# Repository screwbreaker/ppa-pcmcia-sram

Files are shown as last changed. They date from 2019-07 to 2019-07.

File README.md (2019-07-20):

# SAKURA, Amiga pcmcia sram
4MB of Fast RAM for unexpanded Amiga 600/1200.
Original desig by Jarosław Bieliński and Radosław Kujawa.
The informations about the original version of this board can be found here: https://github.com/Sakura-IT/ppa-pcmcia-sram

Since the original version, some components, like the RAM, are became difficult to find, so, many revisions of this board was made in order to use available components.
In 2018 the project was updated again and ported to KiCad by jensma: https://github.com/jensma/ppa-pcmcia-sram
This revision is based on his work.

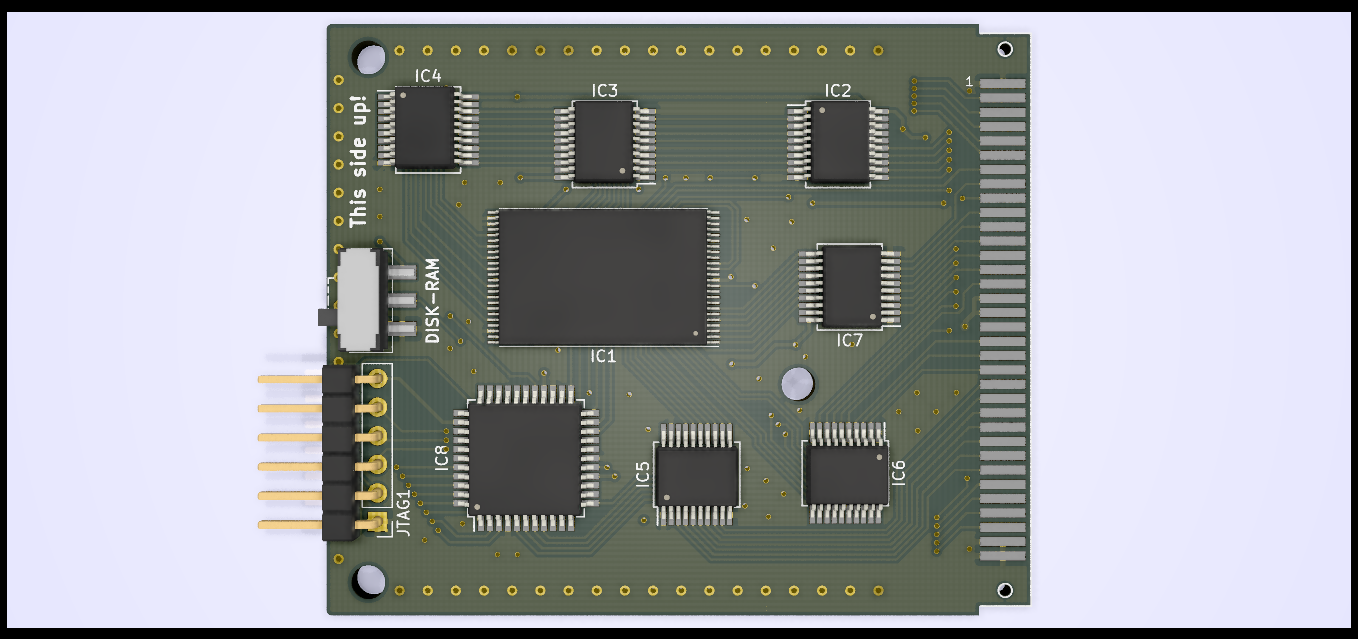
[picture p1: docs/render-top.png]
Board


### Summary
Some components like the RAM are available but not cheap. On the jensma revision also the PCB was not cheap, because he used small tracks and vias.
The main goal of this revision is to made the PCB as cheaper as possible. This make this expansion a little more affordable.

#### BOM
- C14,C3,C5,C6,C7,C8,C9,C10,C11,C12,C13,C4 100nF 0805 ceramic capacitor
- C1,C2: >=10uF >=6,3V 1206 tantalum capacitor
- U1: LM1117-3.3 voltage regulator
- IC2,IC3, IC4 74LCX245MTC
- IC5,IC6,IC7: 74LCX541TTR
- IC1: AS6C3216-55, SRAM
- IC8: XC9536XL_44VQ CPLD
- PCMCIA connector 95622-004LF
- SW1: SW_SPDT_CK-JS102011SAQN

### Installation
Since this board don't have a proper PCMCIA case it must be inserted carefully.
Do not apply too much force, or the pin iside the Amiga connector can be damaged.
There is a maker on the board to identify the upper side.

### License
This board is Open Hardware. If you make any modifications to the board, please contribute them back.

### Disclaimer
This board is provided to you 'as is' and without any express or implied warranties whatsoever with respect to its functionality, operability or use, including, without limitation, any implied warranties of merchantability, fitness for a particular purpose or infringement. We expressly disclaim any liability whatsoever for any direct, indirect, consequential, incidental or special damages, including, without limitation, lost revenues, lost profits, losses resulting from business interruption or loss of data, regardless of the form of action or legal theory under which the liability may be asserted, even if advised of the possibility or likelihood of such damages.

### Thanks
- A special Thanks to: [EmberHeavyIndustries](https://github.com/EmberHeavyIndustries) for the help in the development.
- DanyPPC who started the discussion, [SukkoPera](https://github.com/SukkoPera), Mck, and all the other guys on the Italian Amiga forum [Amigapage](https://www.amigapage.it/index.php?op=v&pl=forum&id=F012019-2-9&page=1)

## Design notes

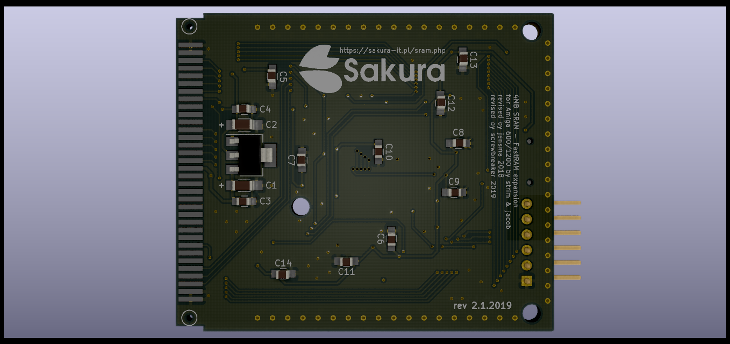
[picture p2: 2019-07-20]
docs/render-bottom.png

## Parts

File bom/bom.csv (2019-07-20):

Id | Designator | Package | Quantity | Designation | Supplier and ref
1 | SW1 | SW_SPDT_CK-JS102011SAQN | 1 | RAM/Disk
2 | C14,C3,C5,C6,C7,C8,C9,C10,C11,C12,C13,C4 | C_0805_HandSoldering | 12 | 0,1uF
3 | C1,C2 | C_1206_HandSoldering | 2 | 10uF/6,3V
4 | U1 | SOT-223-3_TabPin2 | 1 | LM1117-3.3
5 | IC2,IC3,IC4 | SSOP-20_5.3x7.2mm_Pitch0.65mm | 3 | 74LCX245MTC
6 | IC5,IC6,IC7 | SSOP-20_5.3x7.2mm_Pitch0.65mm | 3 | 74LCX541TTR
7 | JTAG1 | Socket_Strip_Straight_1x06_Pitch2.54mm | 1 | MA06-1
8 | X1 | pcmcia | 1 | PCMCIA female
9 | IC1 | TSOP-I-48_18.4x12mm_Pitch0.5mm | 1 | AS6C3216-55
10 | IC8 | TQFP-44_10x10mm_Pitch0.8mm | 1 | XC9536XL_44VQ

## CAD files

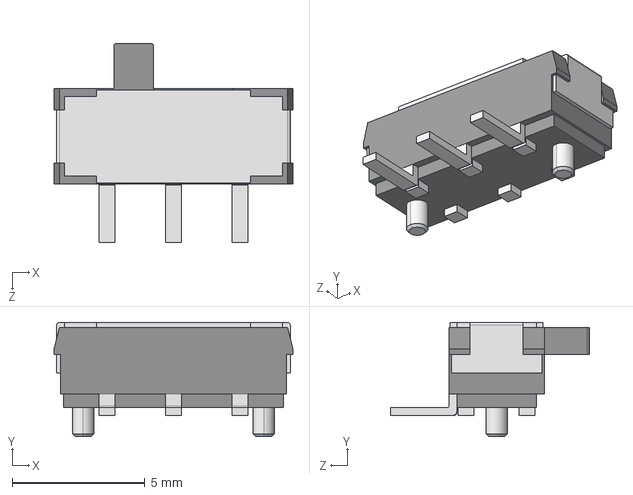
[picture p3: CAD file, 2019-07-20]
3Dmodels/JS102011SAQN.STEP
9.00 x 4.30 x 7.50 mm

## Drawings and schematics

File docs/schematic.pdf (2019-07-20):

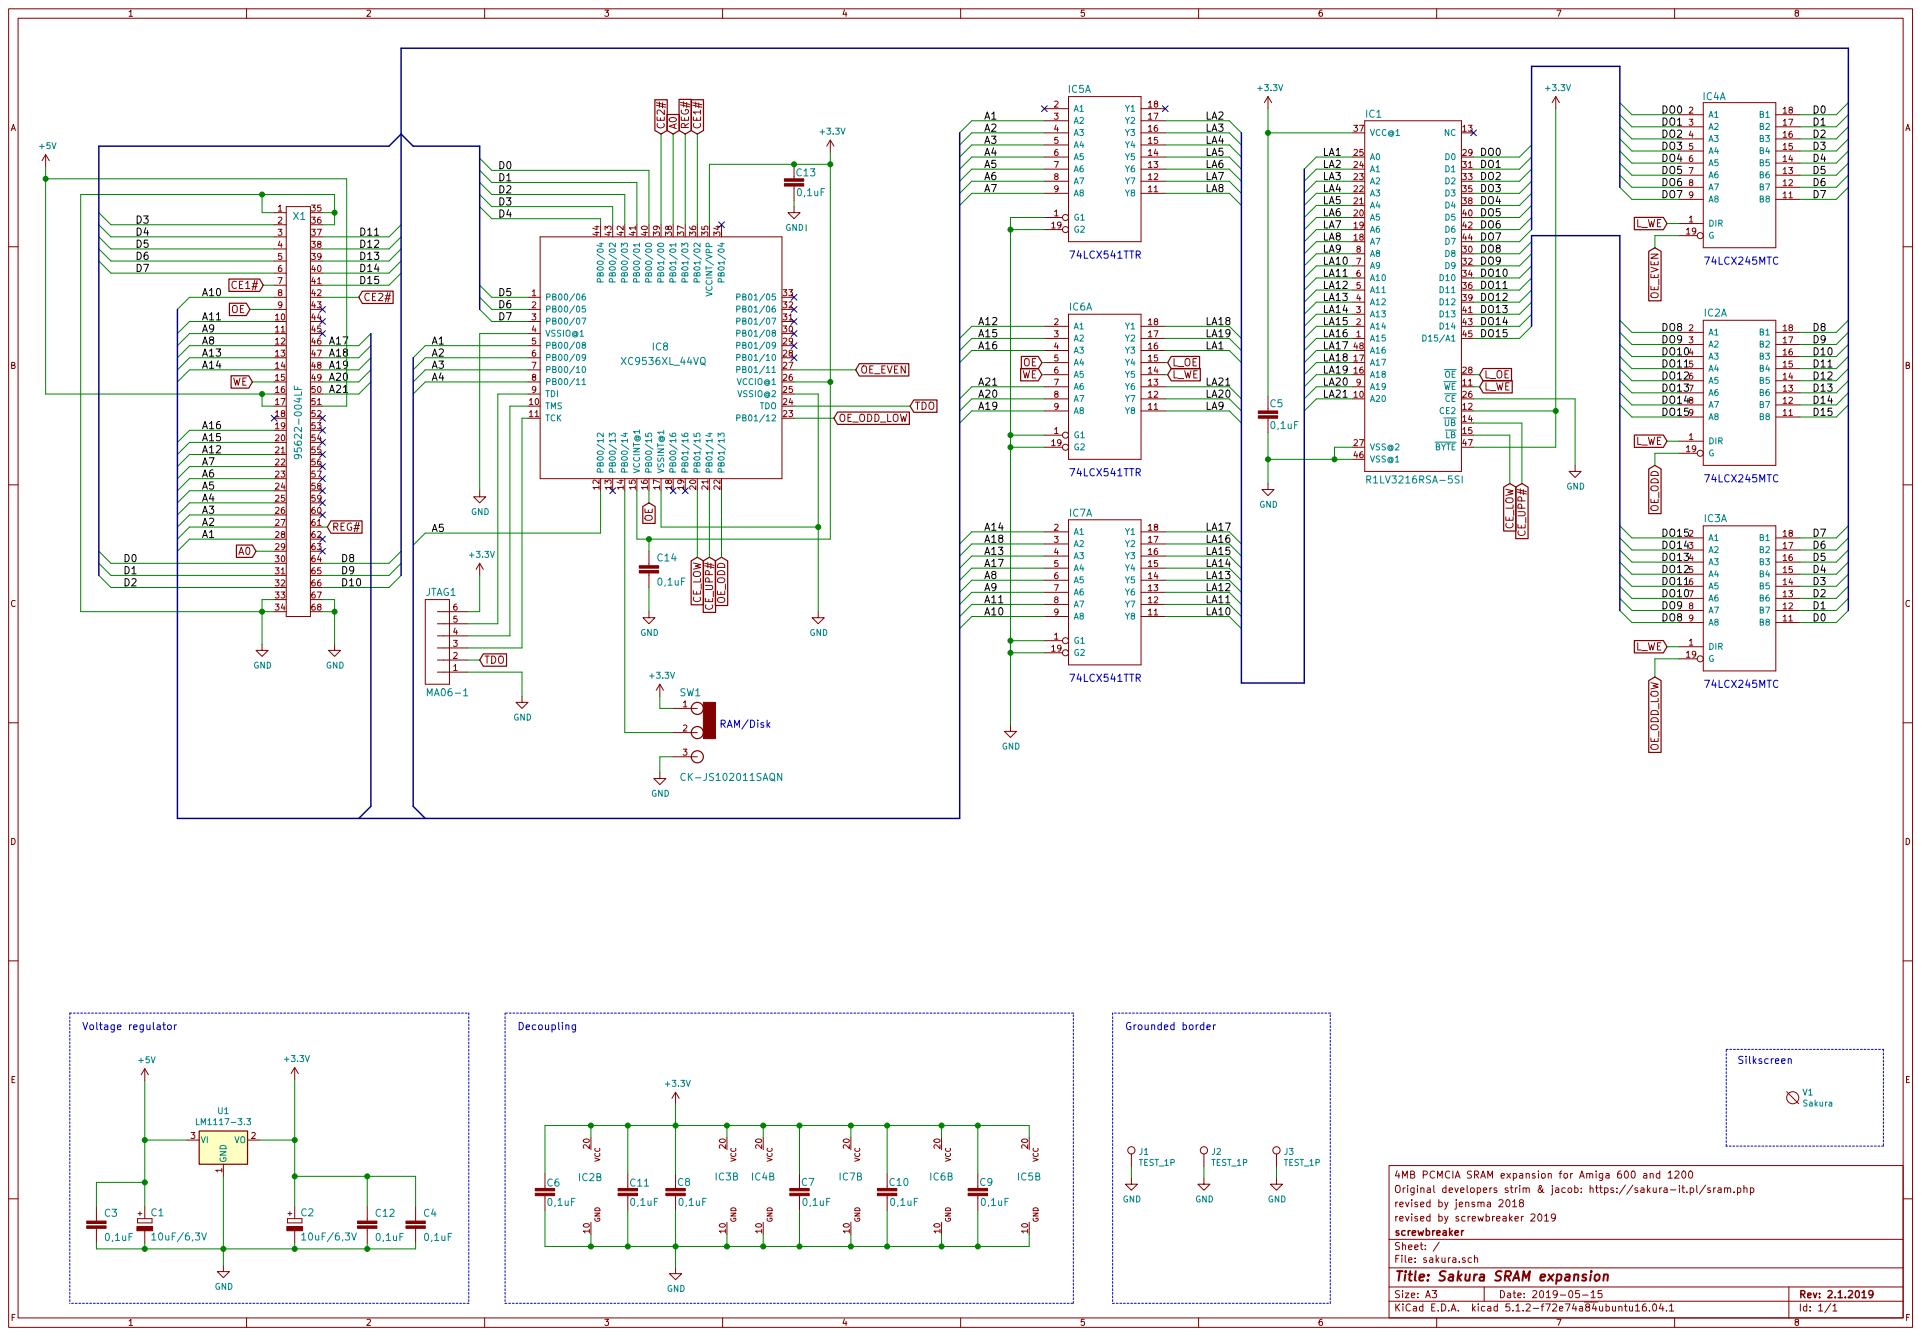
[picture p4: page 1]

4MB PCMCIA SRAM expansion for Amiga 600 and 1200
Original developers strim & jacob: https://sakura-it.pl/sram.php
revised by jensma 2018
revised by screwbreaker 2019
File: sakura.sch Sheet: / screwbreaker

Id: 1/1 Title: Sakura SRAM expansion

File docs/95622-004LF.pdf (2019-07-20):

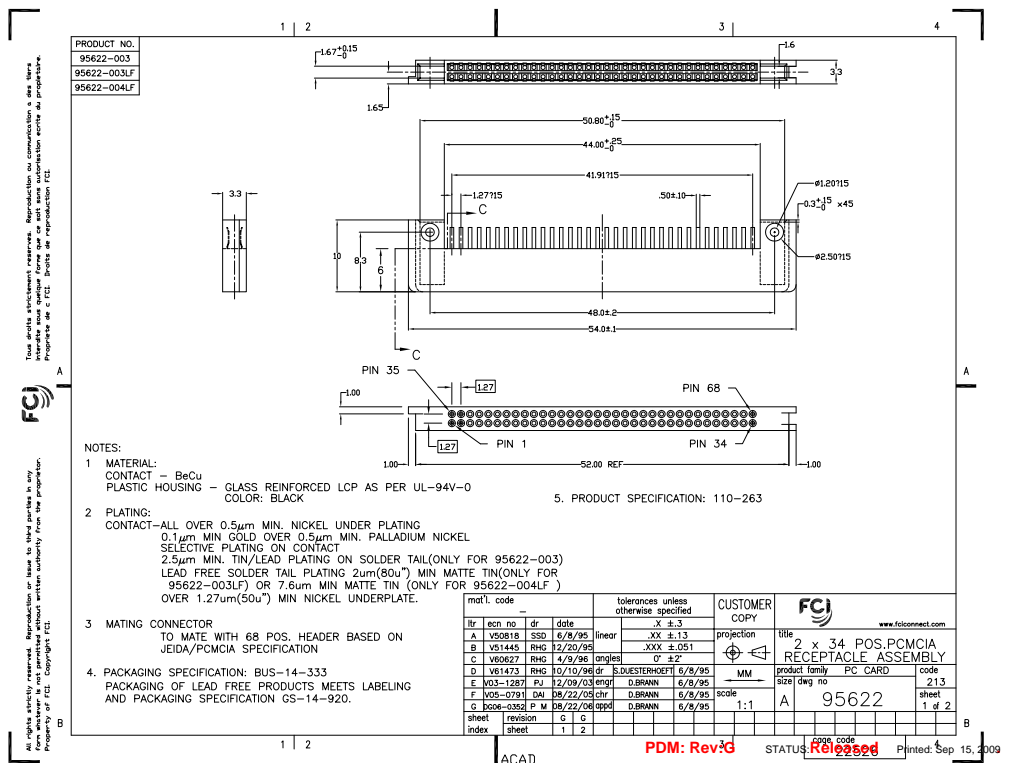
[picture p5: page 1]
PDM: Rev:G; Released; . STATUS:; Printed: Sep 15, 2009

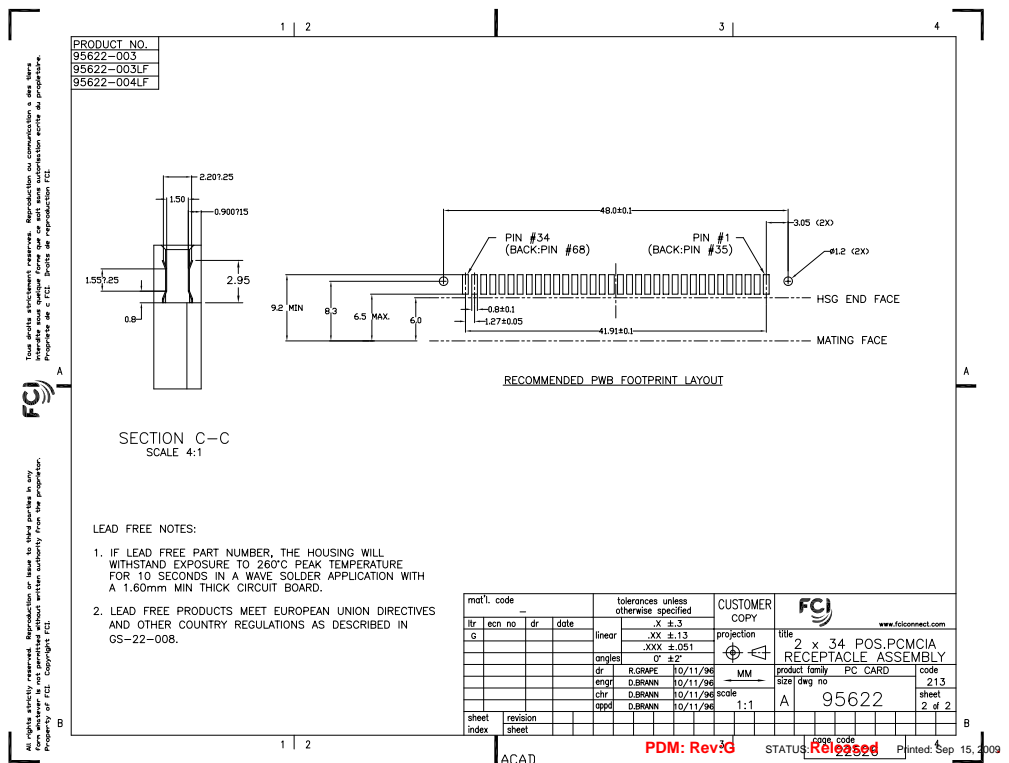
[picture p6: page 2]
PDM: Rev:G; Released; . STATUS:; Printed: Sep 15, 2009

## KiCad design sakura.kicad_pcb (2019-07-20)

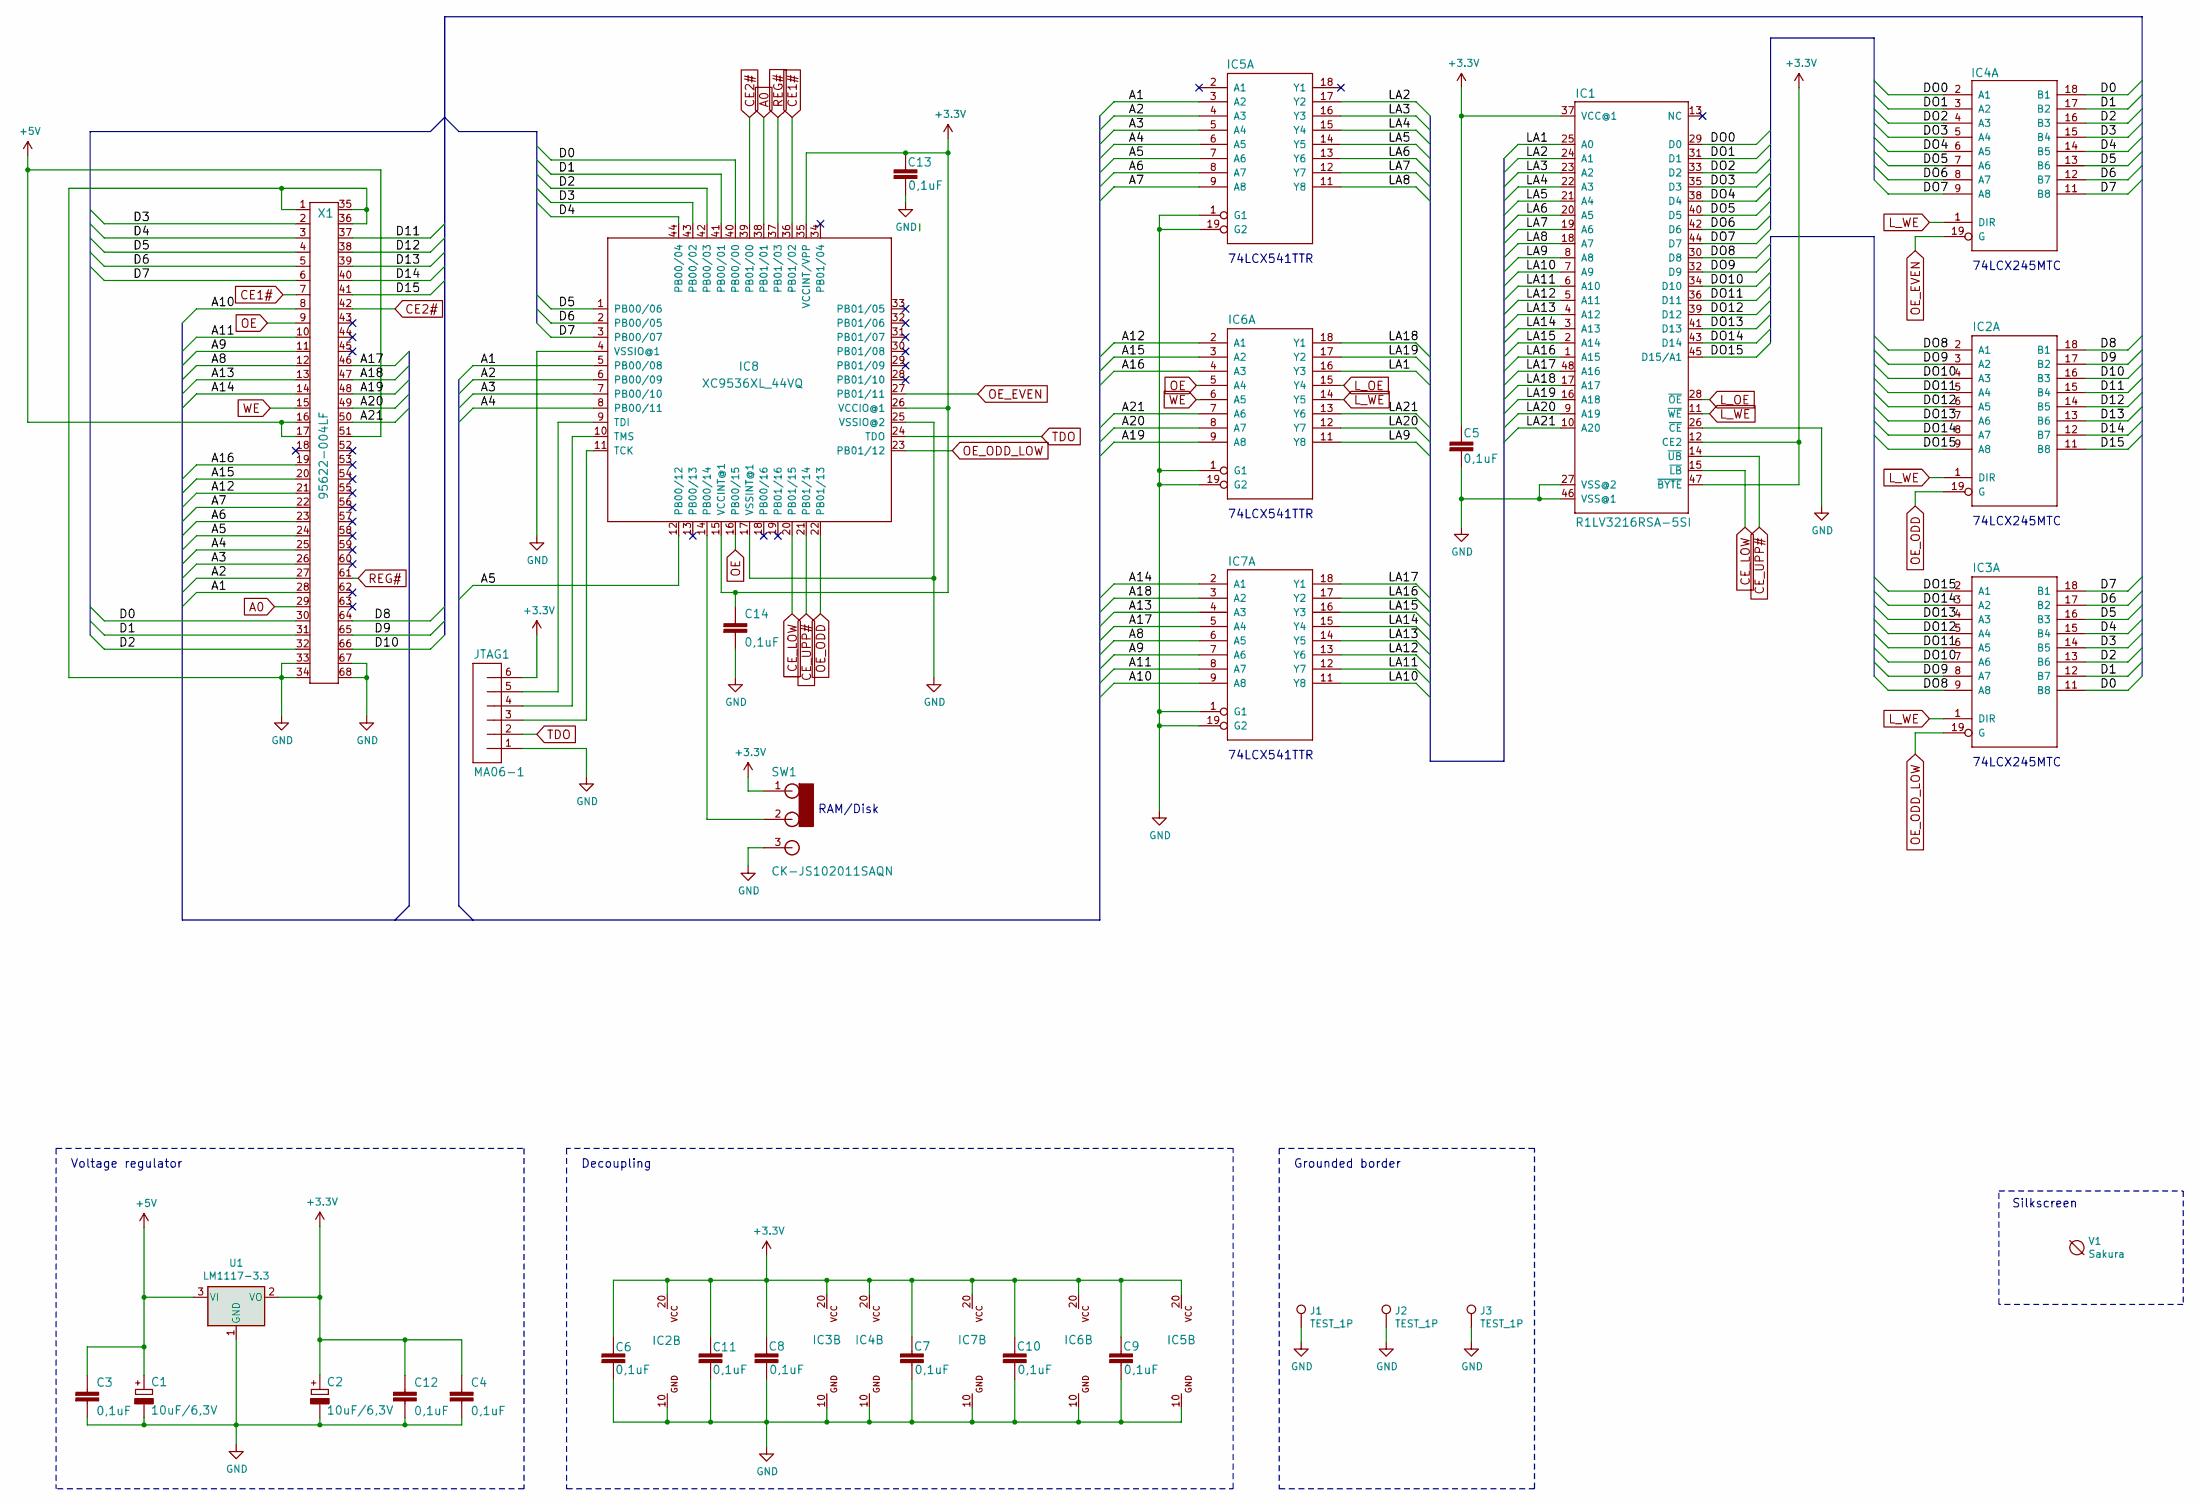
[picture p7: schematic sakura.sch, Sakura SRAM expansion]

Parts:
C1, C2: 10uF/6,3V; C_1206_HandSoldering
C3, C4, C5, C6, C7, C8, C9, C10, C11, C12, C13, C14: 0,1uF; C_0805_HandSoldering
IC1: R1LV3216RSA-5SI; TSOP-I-48_18.4x12mm_Pitch0.5mm
IC2, IC3, IC4: 74LCX245MTC; SSOP-20_5.3x7.2mm_Pitch0.65mm
IC5, IC6, IC7: 74LCX541TTR; SSOP-20_5.3x7.2mm_Pitch0.65mm
IC8: XC9536XL_44VQ; TQFP-44_10x10mm_Pitch0.8mm
J1, J2, J3: TEST_1P; viabar
JTAG1: MA06-1; Socket_Strip_Straight_1x06_Pitch2.54mm
SW1: CK-JS102011SAQN; SW_SPDT_CK-JS102011SAQN
U1: LM1117-3.3; SOT-223-3_TabPin2
V1: Sakura; logo
X1: 95622-004LF; pcmcia

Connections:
+3V3: C2.1 (+), C4.1, C5.1, C6.1, C7.1, C8.1, C9.1, C10.1, C11.1, C12.1, C13.1, C14.1, IC1.12 (CE2), IC1.37 (VCC@1), IC1.47 (~BYTE), IC2.20 (VCC), IC3.20 (VCC), IC4.20 (VCC), IC5.20 (VCC), IC6.20 (VCC), IC7.20 (VCC), IC8.15 (VCCINT@1), IC8.26 (VCCIO@1), IC8.35 (VCCINT/VPP), JTAG1.6, SW1.1, U1.2 (VO)
+5V: C1.1 (+), C3.1, U1.3 (VI), X1.16, X1.17, X1.51
/A1: IC5.3 (A2), IC8.5 (PB00/08), X1.28
/A2: IC5.4 (A3), IC8.6 (PB00/09), X1.27
/A3: IC5.5 (A4), IC8.7 (PB00/10), X1.26
/A4: IC5.6 (A5), IC8.8 (PB00/11), X1.25
/A5: IC5.7 (A6), IC8.12 (PB00/12), X1.24
/A6: IC5.8 (A7), X1.23
/A7: IC5.9 (A8), X1.22
/A8: IC7.6 (A5), X1.12
/A9: IC7.7 (A6), X1.11
/A10: IC7.9 (A8), X1.8
/A11: IC7.8 (A7), X1.10
/A12: IC6.2 (A1), X1.21
/A13: IC7.4 (A3), X1.13
/A14: IC7.2 (A1), X1.14
/A15: IC6.3 (A2), X1.20
/A16: IC6.4 (A3), X1.19
/A17: IC7.5 (A4), X1.46
/A18: IC7.3 (A2), X1.47
/A19: IC6.9 (A8), X1.48
/A20: IC6.8 (A7), X1.49
/A21: IC6.7 (A6), X1.50
/D0: IC3.11 (B8), IC4.18 (B1), IC8.40 (PB00/00), X1.30
/D1: IC3.12 (B7), IC4.17 (B2), IC8.41 (PB00/01), X1.31
/D2: IC3.13 (B6), IC4.16 (B3), IC8.42 (PB00/03), X1.32
/D3: IC3.14 (B5), IC4.15 (B4), IC8.43 (PB00/02), X1.2
/D4: IC3.15 (B4), IC4.14 (B5), IC8.44 (PB00/04), X1.3
/D5: IC3.16 (B3), IC4.13 (B6), IC8.1 (PB00/06), X1.4
/D6: IC3.17 (B2), IC4.12 (B7), IC8.2 (PB00/05), X1.5
/D7: IC3.18 (B1), IC4.11 (B8), IC8.3 (PB00/07), X1.6
/D8: IC2.18 (B1), X1.64
/D9: IC2.17 (B2), X1.65
/D10: IC2.16 (B3), X1.66
/D11: IC2.15 (B4), X1.37
/D12: IC2.14 (B5), X1.38
/D13: IC2.13 (B6), X1.39
/D14: IC2.12 (B7), X1.40
/D15: IC2.11 (B8), X1.41
/DO0: IC1.29 (D0), IC4.2 (A1)
/DO1: IC1.31 (D1), IC4.3 (A2)
/DO2: IC1.33 (D2), IC4.4 (A3)
/DO3: IC1.35 (D3), IC4.5 (A4)
/DO4: IC1.38 (D4), IC4.6 (A5)
/DO5: IC1.40 (D5), IC4.7 (A6)
/DO6: IC1.42 (D6), IC4.8 (A7)
/DO7: IC1.44 (D7), IC4.9 (A8)
/DO8: IC1.30 (D8), IC2.2 (A1), IC3.9 (A8)
/DO9: IC1.32 (D9), IC2.3 (A2), IC3.8 (A7)
/DO10: IC1.34 (D10), IC2.4 (A3), IC3.7 (A6)
/DO11: IC1.36 (D11), IC2.5 (A4), IC3.6 (A5)
/DO12: IC1.39 (D12), IC2.6 (A5), IC3.5 (A4)
/DO13: IC1.41 (D13), IC2.7 (A6), IC3.4 (A3)
/DO14: IC1.43 (D14), IC2.8 (A7), IC3.3 (A2)
/DO15: IC1.45 (D15/A1), IC2.9 (A8), IC3.2 (A1)
/LA1: IC1.25 (A0), IC6.16 (Y3)
/LA2: IC1.24 (A1), IC5.17 (Y2)
/LA3: IC1.23 (A2), IC5.16 (Y3)
/LA4: IC1.22 (A3), IC5.15 (Y4)
/LA5: IC1.21 (A4), IC5.14 (Y5)
/LA6: IC1.20 (A5), IC5.13 (Y6)
/LA7: IC1.19 (A6), IC5.12 (Y7)
/LA8: IC1.18 (A7), IC5.11 (Y8)
/LA9: IC1.8 (A8), IC6.11 (Y8)
/LA10: IC1.7 (A9), IC7.11 (Y8)
/LA11: IC1.6 (A10), IC7.12 (Y7)
/LA12: IC1.5 (A11), IC7.13 (Y6)
/LA13: IC1.4 (A12), IC7.14 (Y5)
/LA14: IC1.3 (A13), IC7.15 (Y4)
/LA15: IC1.2 (A14), IC7.16 (Y3)
/LA16: IC1.1 (A15), IC7.17 (Y2)
/LA17: IC1.48 (A16), IC7.18 (Y1)
/LA18: IC1.17 (A17), IC6.18 (Y1)
/LA19: IC1.16 (A18), IC6.17 (Y2)
/LA20: IC1.9 (A19), IC6.12 (Y7)
/LA21: IC1.10 (A20), IC6.13 (Y6)
A0: IC8.38 (PB01/01), X1.29
CE1#: IC8.36 (PB01/02), X1.7
CE2#: IC8.39 (PB01/00), X1.42
CE_LOW: IC1.15 (~LB), IC8.20 (PB01/15)
CE_UPP#: IC1.14 (~UB), IC8.21 (PB01/14)
GND: C1.2 (-), C2.2 (-), C3.2, C4.2, C5.2, C6.2, C7.2, C8.2, C9.2, C10.2, C11.2, C12.2, C13.2, C14.2, IC1.26 (~CE), IC1.27 (VSS@2), IC1.46 (VSS@1), IC2.10 (GND), IC3.10 (GND), IC4.10 (GND), IC5.1 (G1), IC5.10 (GND), IC5.19 (G2), IC6.1 (G1), IC6.10 (GND), IC6.19 (G2), IC7.1 (G1), IC7.10 (GND), IC7.19 (G2), IC8.4 (VSSIO@1), IC8.17 (VSSINT@1), IC8.25 (VSSIO@2), J1.1, J2.1, J3.1, JTAG1.1, SW1.3, U1.1 (GND), X1.1, X1.33, X1.34, X1.35, X1.36, X1.67, X1.68
L_OE: IC1.28 (~OE), IC6.15 (Y4)
L_WE: IC1.11 (~WE), IC2.1 (DIR), IC3.1 (DIR), IC4.1 (DIR), IC6.14 (Y5)
unnamed: IC8.9 (TDI), JTAG1.5
unnamed: IC8.10 (TMS), JTAG1.4
unnamed: IC8.11 (TCK), JTAG1.3
unnamed: IC8.14 (PB00/14), SW1.2
OE: IC6.5 (A4), IC8.16 (PB00/15), X1.9
OE_EVEN: IC4.19 (G), IC8.27 (PB01/11)
OE_ODD: IC2.19 (G), IC8.22 (PB01/13)
OE_ODD_LOW: IC3.19 (G), IC8.23 (PB01/12)
REG#: IC8.37 (PB01/03), X1.61
TDO: IC8.24 (TDO), JTAG1.2
WE: IC6.6 (A5), X1.15

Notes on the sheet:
74LCX541TTR
74LCX245MTC
Grounded border
Decoupling
Voltage regulator
Silkscreen
RAM/Disk

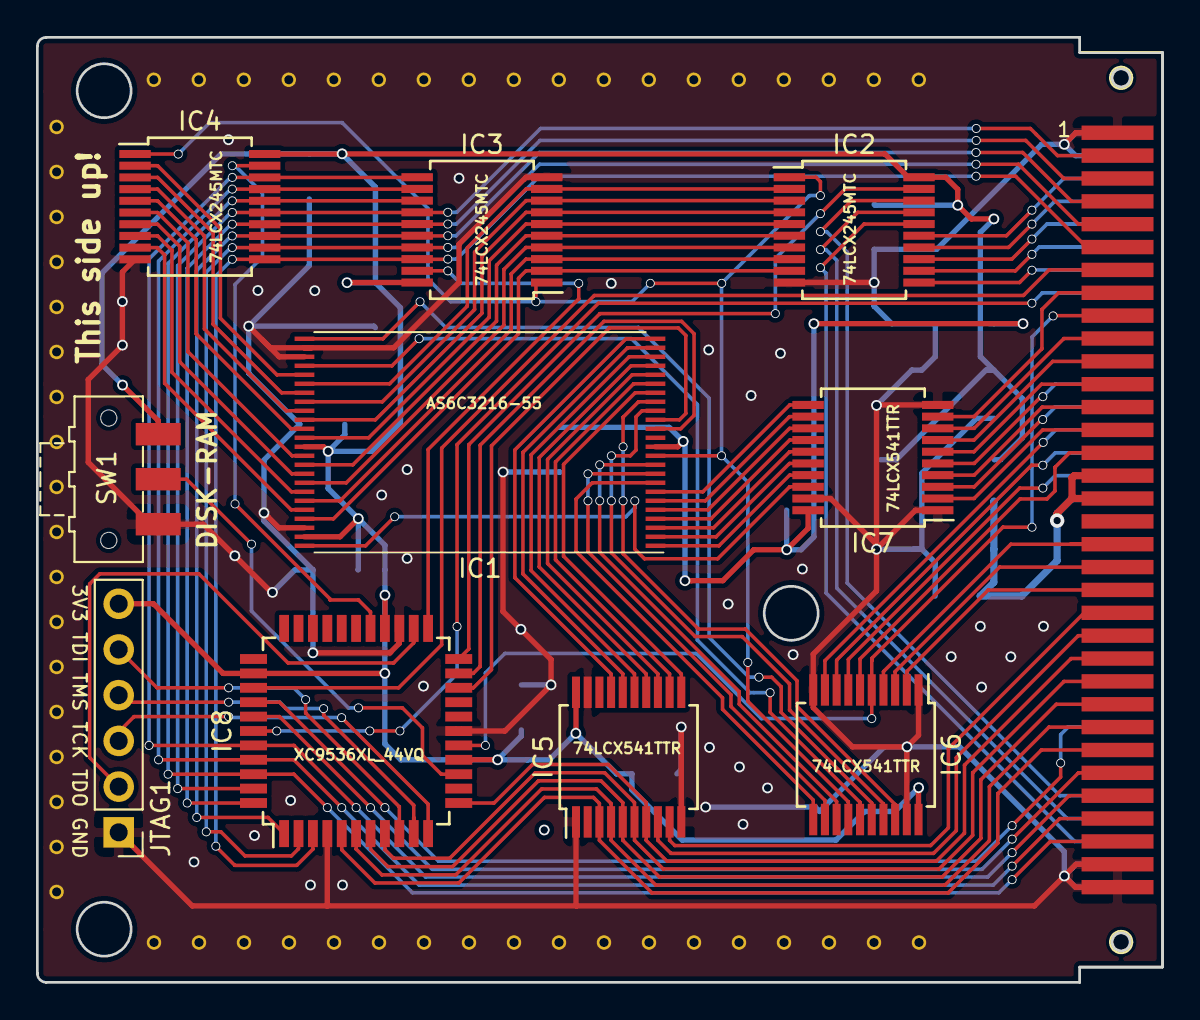
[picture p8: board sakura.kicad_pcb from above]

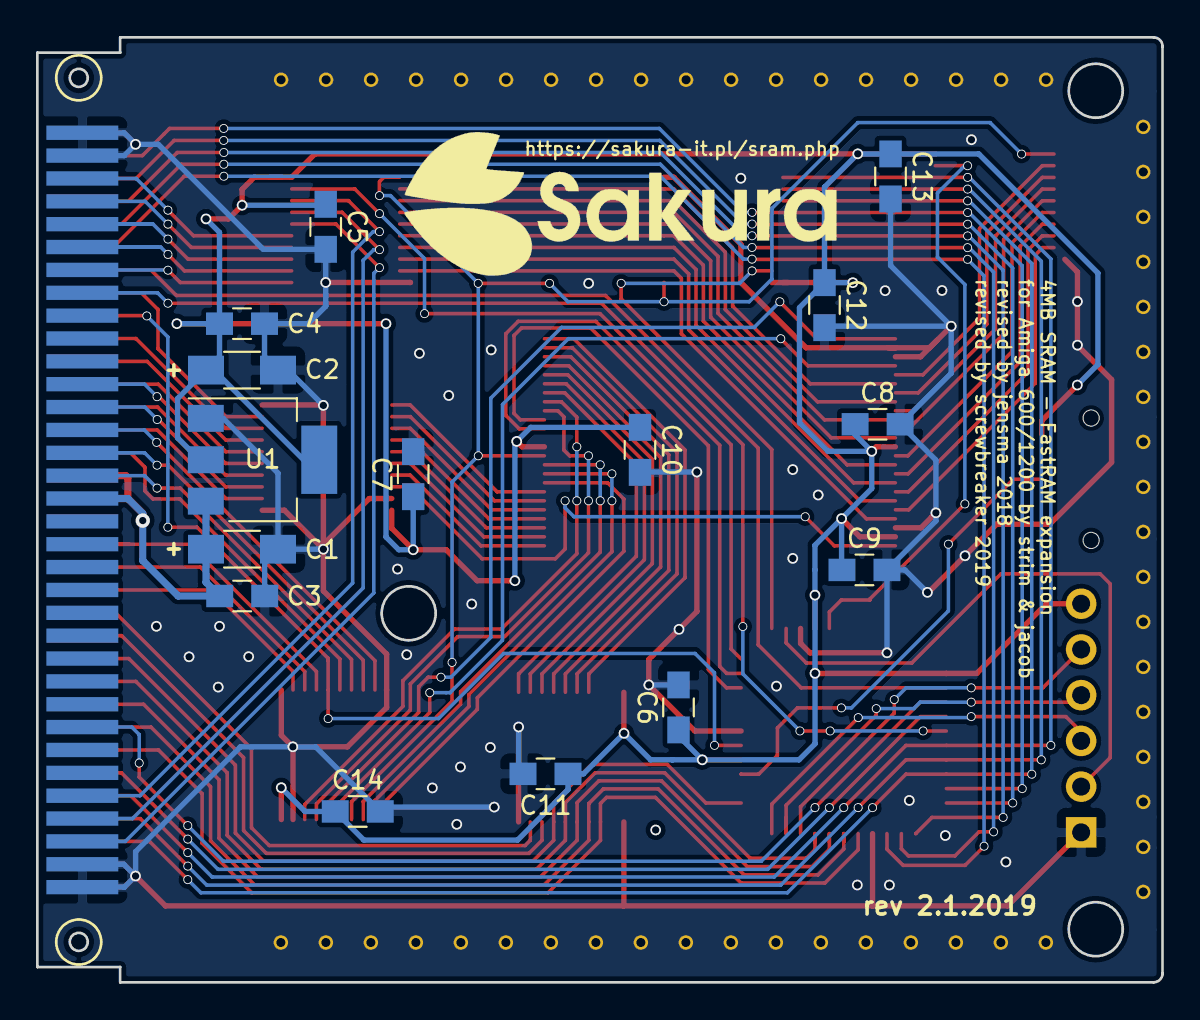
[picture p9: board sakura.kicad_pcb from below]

Board: 2 copper layers, 62.5 x 52.5 mm, 30 parts (16 on the bottom side), 95 nets.

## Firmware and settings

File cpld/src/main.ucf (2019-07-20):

# control signals from PCMCIA
NET "ce1" LOC = "36";
NET "ce2" LOC = "39";
NET "a0" LOC = "38"; # address bus bit 0
NET "reg" LOC = "37";
NET "oe_rom" LOC = "16";  # OE from PCMCIA in fact only used by ROM

# switches/jumpers
NET "sw_rom" LOC = "14";

# control signals to memory
NET "oe_even" LOC = "27";
NET "oe_oddlow" LOC = "23";
NET "oe_odd" LOC = "22";
NET "ce_upp" LOC = "21";
NET "ce_low" LOC = "20";
NET "ce_attr_external" LOC = "19";

# address bus (in fact A1-A5)
NET "addr<0>" LOC = "5";
NET "addr<1>" LOC = "6";
NET "addr<2>" LOC = "7";
NET "addr<3>" LOC = "8";
NET "addr<4>" LOC = "12";

# lowest 8 bits of data bus
NET "data<0>" LOC = "40";
NET "data<1>" LOC = "41";
NET "data<2>" LOC = "42";
NET "data<3>" LOC = "43";
NET "data<4>" LOC = "44";
NET "data<5>" LOC = "1";
NET "data<6>" LOC = "2";
NET "data<7>" LOC = "3";

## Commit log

2018-11-14 revised for 2018 + added kicad sources
2019-07-20 switch 3D model
    [JS102011SAQN.STEP]
2019-07-20 interactive BOM
2019-07-20 PCMCIA connector datasheet
